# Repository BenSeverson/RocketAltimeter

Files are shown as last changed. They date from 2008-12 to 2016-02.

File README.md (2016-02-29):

High Power Rocket Altimeter
===============
This is an altimeter for [high power rocketry](https://en.wikipedia.org/wiki/High-power_rocketry). Sources include the PIC Micro firmware, Eagle PCB layout, and Windows configuration/log download program.

Features:
- dual payload deployment
- altitude and deployment logging to non-volatile EEPROM
- native USB support for configuration and log downloading
- audible max altitude readout
- pre-launch readiness audible indicator and rocket recovery/location beep
- simple 2-layer PCB with mainly SMT components designed to be made at home

**Note:** I started this project back in 2007 when I was in college but life got in the way before I had a chance to complete it. I've uploaded it here for archival purposes and maybe someone will find it useful. If you are looking for an open source altimeter, I'd highly suggest [Altus Metrum](http://altusmetrum.org/) which is complete, much more advanced, and actually being developed/maintained.

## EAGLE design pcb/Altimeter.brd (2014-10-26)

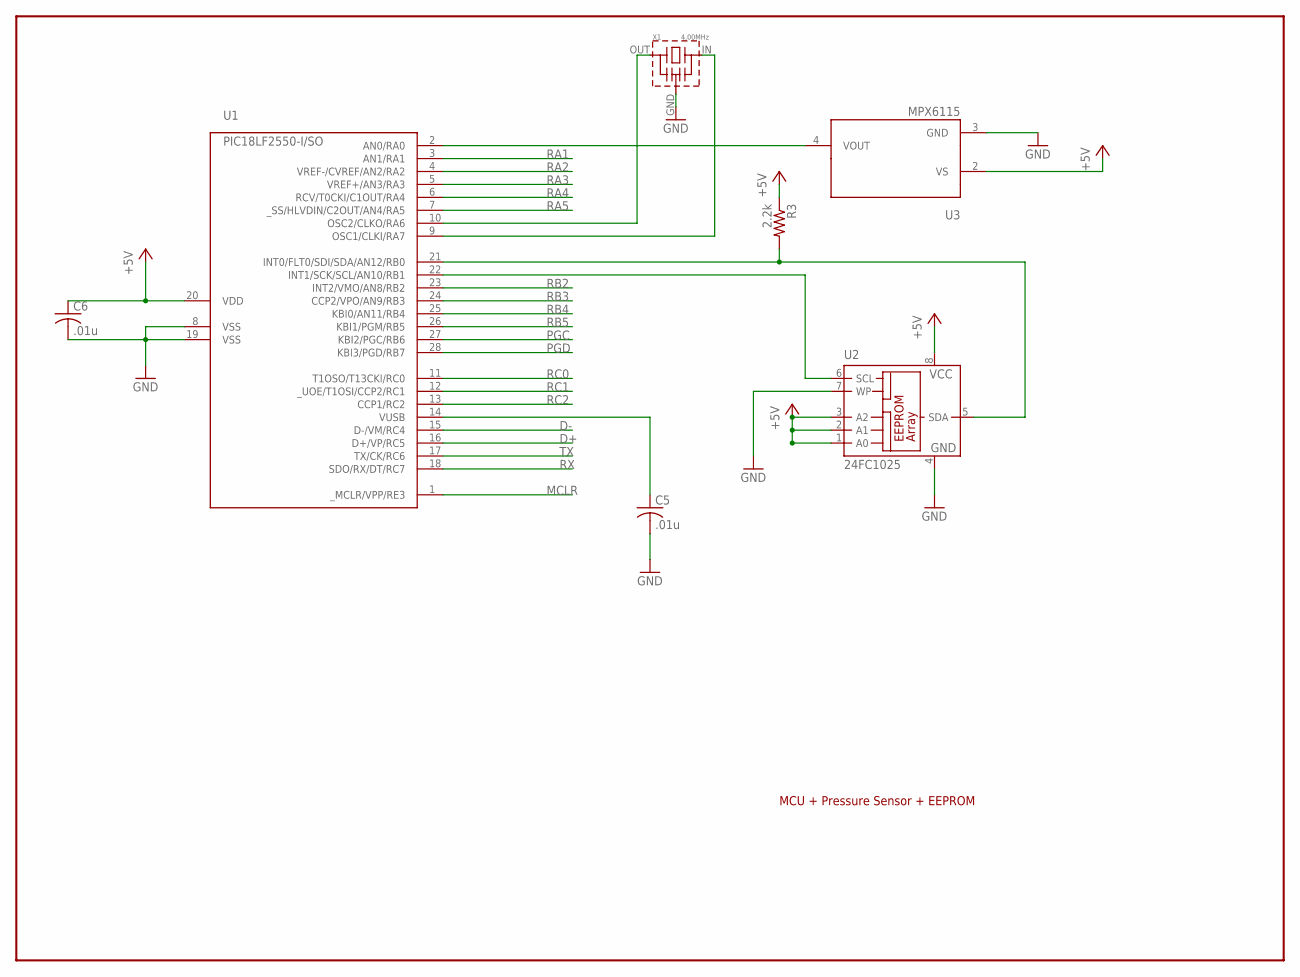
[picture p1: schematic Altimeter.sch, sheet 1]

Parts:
C5, C6: .01u; C1206
R3: 2.2k; R1206
U1: PIC18LF2550-I/SO; SO-28W
U2: 24FC1025; SO-08M
U3: MPX6115; SSOP8
X1: 4.00MHz; 7434

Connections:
+5V: C6.1, R3.1, U1.20 (VDD), U2.1 (A0), U2.2 (A1), U2.3 (A2), U2.8 (VCC), U3.2 (VS); also elsewhere on the board
D+: U1.16 (D+/VP/RC5); also elsewhere on the board
D-: U1.15 (D-/VM/RC4); also elsewhere on the board
GND: C5.2, C6.2, U1.8 (VSS), U1.19 (VSS), U2.4 (GND), U2.7 (WP), U3.3 (GND), X1.GND (VSS); also elsewhere on the board
MCLR: U1.1 (_MCLR/VPP/RE3); also elsewhere on the board
unnamed: U1.2 (AN0/RA0), U3.4 (VOUT)
unnamed: U1.22 (INT1/SCK/SCL/AN10/RB1), U2.6 (SCL)
unnamed: R3.2, U1.21 (INT0/FLT0/SDI/SDA/AN12/RB0), U2.5 (SDA)
unnamed: U1.10 (OSC2/CLKO/RA6), X1.OUT (1)
unnamed: U1.9 (OSC1/CLKI/RA7), X1.IN (3)
unnamed: C5.1, U1.14 (VUSB)
PGC: U1.27 (KBI2/PGC/RB6); also elsewhere on the board
PGD: U1.28 (KBI3/PGD/RB7); also elsewhere on the board
RA1: U1.3 (AN1/RA1)
RA2: U1.4 (VREF-/CVREF/AN2/RA2)
RA3: U1.5 (VREF+/AN3/RA3); also elsewhere on the board
RA4: U1.6 (RCV/T0CKI/C1OUT/RA4); also elsewhere on the board
RA5: U1.7 (_SS/HLVDIN/C2OUT/AN4/RA5)
RB2: U1.23 (INT2/VMO/AN8/RB2); also elsewhere on the board
RB3: U1.24 (CCP2/VPO/AN9/RB3); also elsewhere on the board
RB4: U1.25 (KBI0/AN11/RB4)
RB5: U1.26 (KBI1/PGM/RB5)
RC0: U1.11 (T1OSO/T13CKI/RC0); also elsewhere on the board
RC1: U1.12 (_UOE/T1OSI/CCP2/RC1); also elsewhere on the board
RC2: U1.13 (CCP1/RC2); also elsewhere on the board
RX: U1.18 (SDO/RX/DT/RC7); also elsewhere on the board
TX: U1.17 (TX/CK/RC6); also elsewhere on the board

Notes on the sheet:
MCU + Pressure Sensor + EEPROM

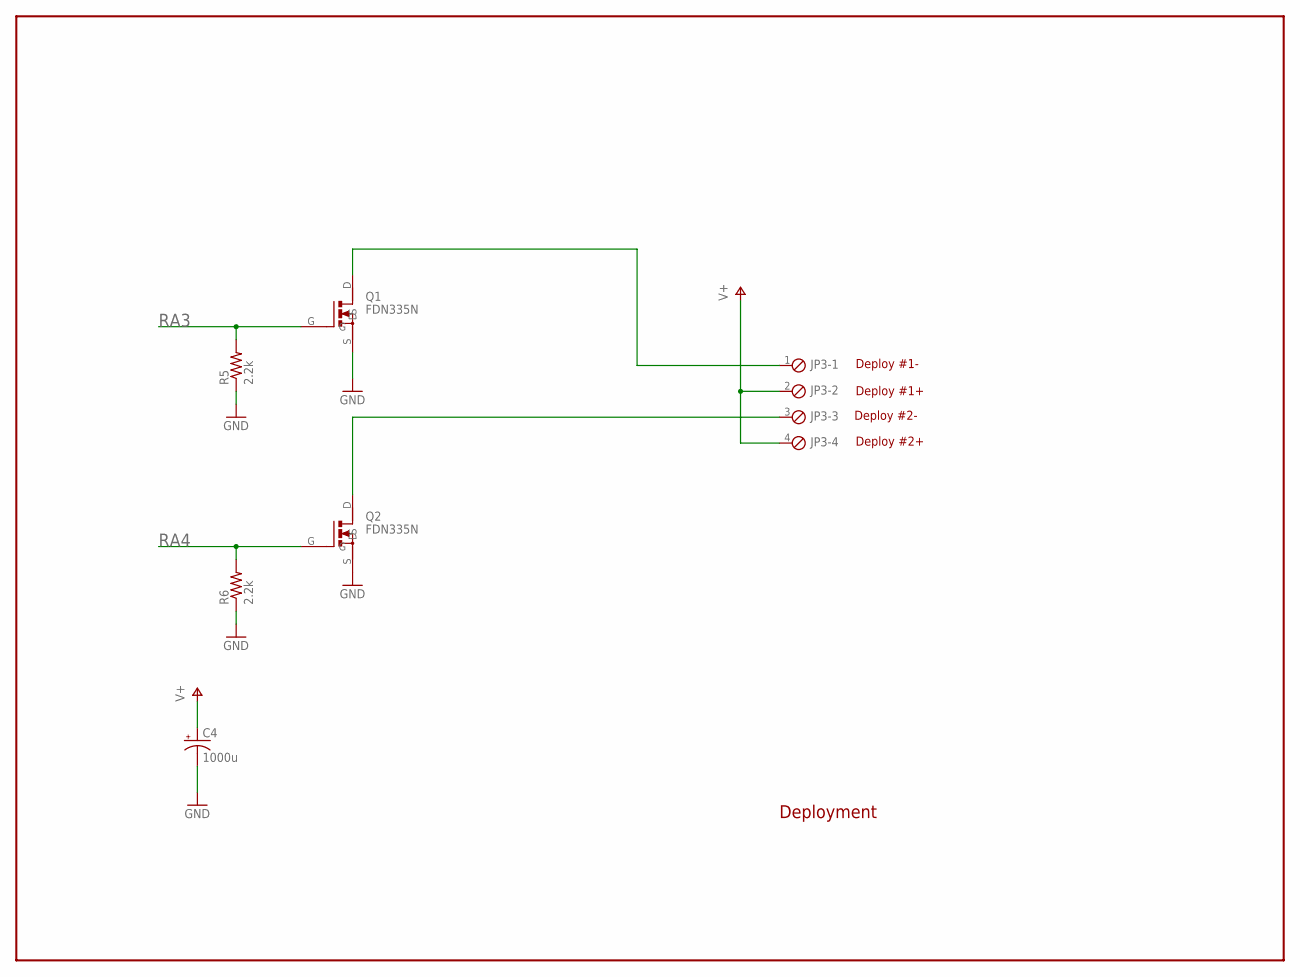
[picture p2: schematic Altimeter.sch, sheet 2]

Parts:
C4: 1000u; PANASONIC_G
JP3: MPT4; 4POL254
Q1, Q2: FDN335N; SSOT3
R5, R6: 2.2k; R1206

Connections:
GND: C4.-, Q1.S, Q2.S, R5.1, R6.1; also elsewhere on the board
unnamed: JP3.1, Q1.D
unnamed: JP3.3, Q2.D
RA3: Q1.G, R5.2; also elsewhere on the board
RA4: Q2.G, R6.2; also elsewhere on the board
V+: C4.+, JP3.2, JP3.4; also elsewhere on the board

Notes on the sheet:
Deployment
Deploy #1-
Deploy #1+
Deploy #2+
Deploy #2-

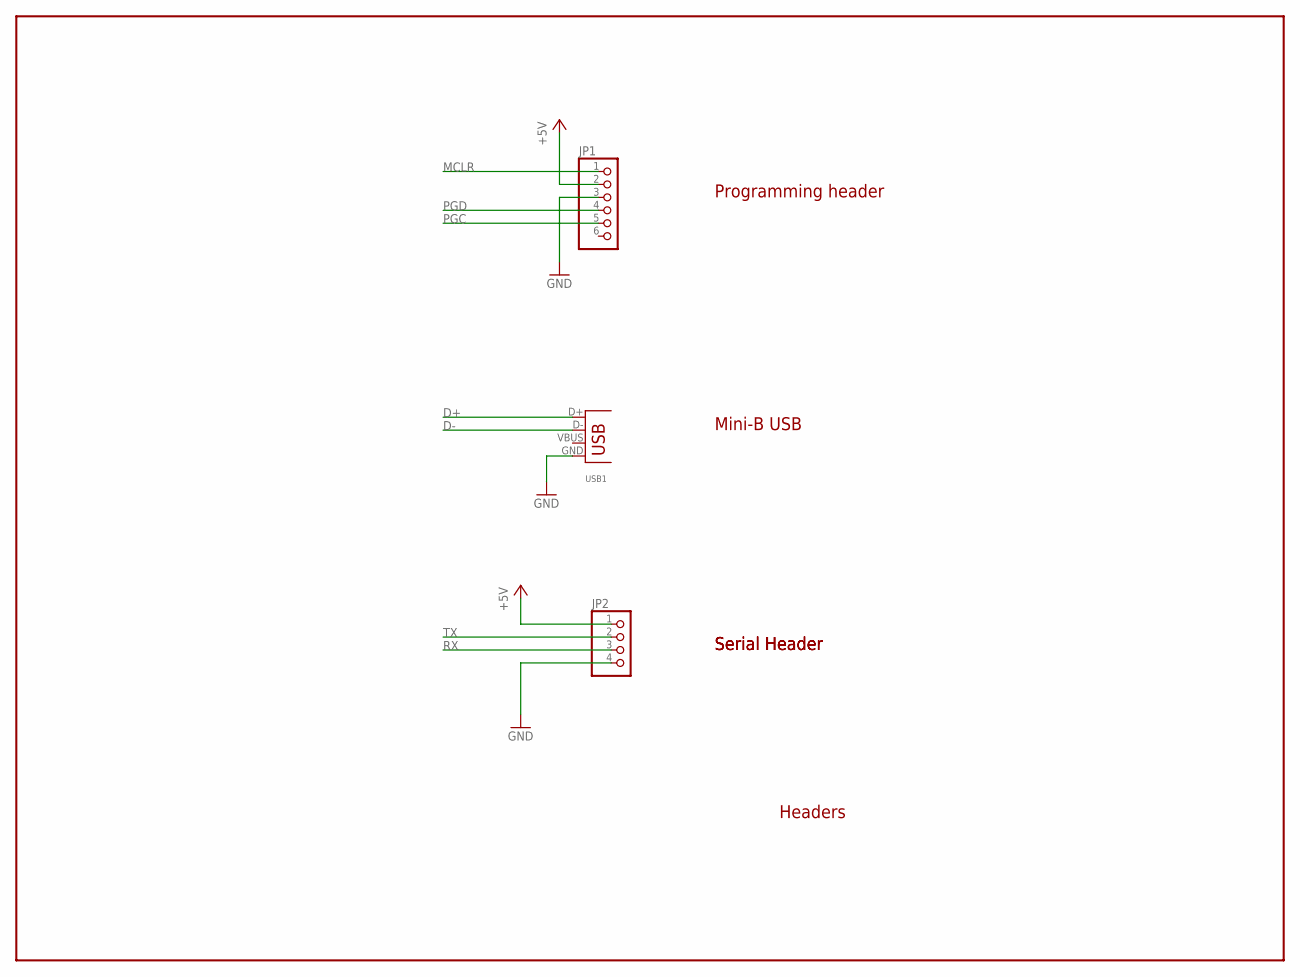
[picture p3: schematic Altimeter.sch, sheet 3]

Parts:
JP1: PINHD-1X6; 1X06
JP2: PINHD-1X4; 1X04
USB1: USB-MB-S

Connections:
+5V: JP1.2, JP2.1; also elsewhere on the board
D+: USB1.D+; also elsewhere on the board
D-: USB1.D-; also elsewhere on the board
GND: JP1.3, JP2.4, USB1.GND; also elsewhere on the board
MCLR: JP1.1; also elsewhere on the board
PGC: JP1.5; also elsewhere on the board
PGD: JP1.4; also elsewhere on the board
RX: JP2.3; also elsewhere on the board
TX: JP2.2; also elsewhere on the board

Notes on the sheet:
Programming header
Mini-B USB
Serial Header
Headers

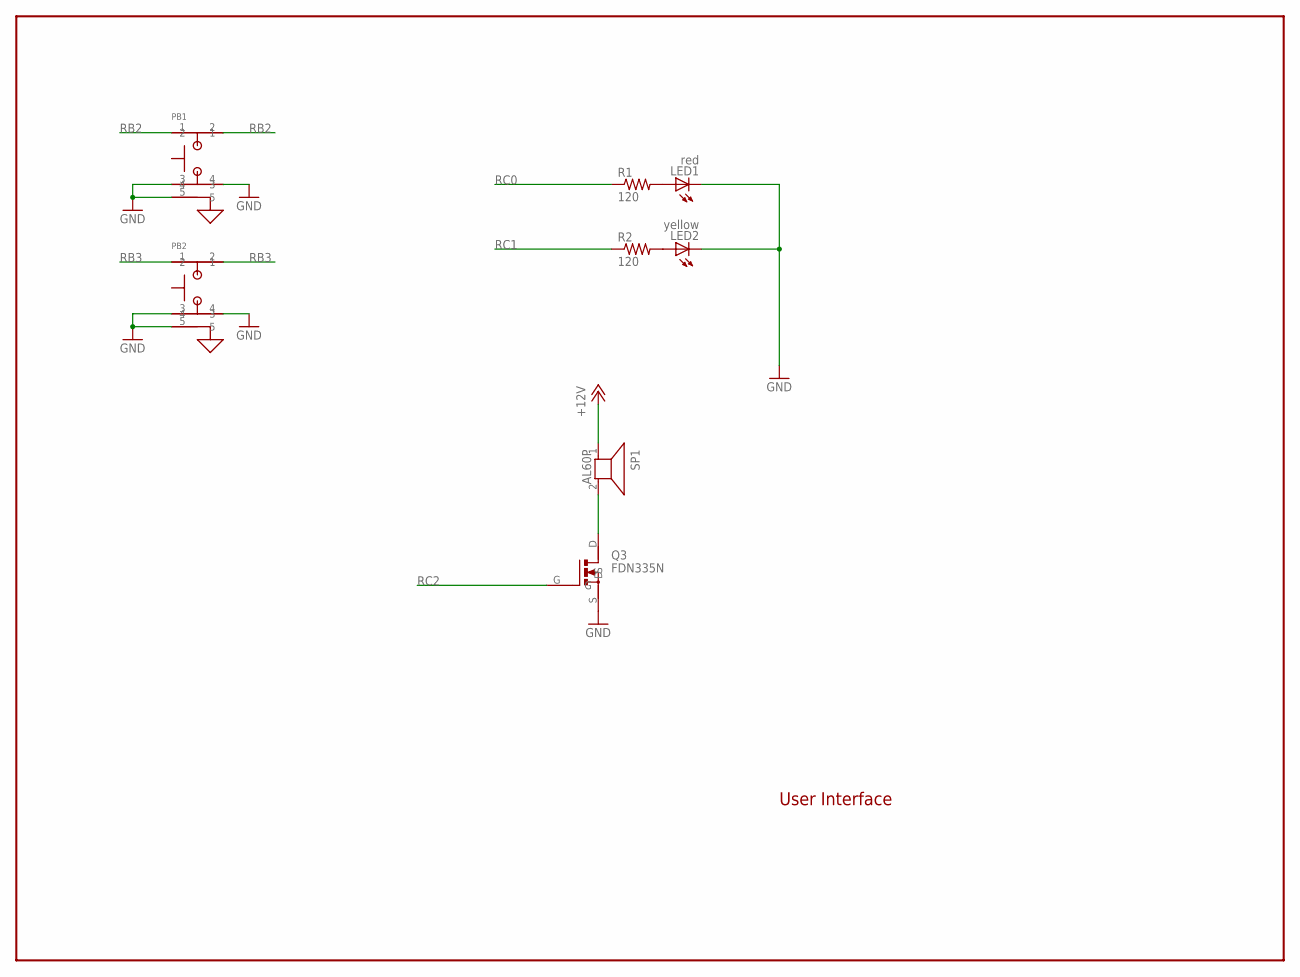
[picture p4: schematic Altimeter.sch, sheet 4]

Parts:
LED1: red; 1206
LED2: yellow; 1206
PB1, PB2: ALPS_SWITCH_SMD; ALPS-SMD-TACT
Q3: FDN335N; SSOT3
R1, R2: 120; R1206
SP1: AL60P; KB-BUZZER

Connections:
+12V: SP1.1; also elsewhere on the board
GND: LED1.C, LED2.C, PB1.3, PB1.4, PB1.5, PB2.3, PB2.4, PB2.5, Q3.S; also elsewhere on the board
unnamed: LED1.A, R1.2
unnamed: LED2.A, R2.2
unnamed: Q3.D, SP1.2
RB2: PB1.1, PB1.2; also elsewhere on the board
RB3: PB2.1, PB2.2; also elsewhere on the board
RC0: R1.1; also elsewhere on the board
RC1: R2.1; also elsewhere on the board
RC2: Q3.G; also elsewhere on the board

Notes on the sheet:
User Interface

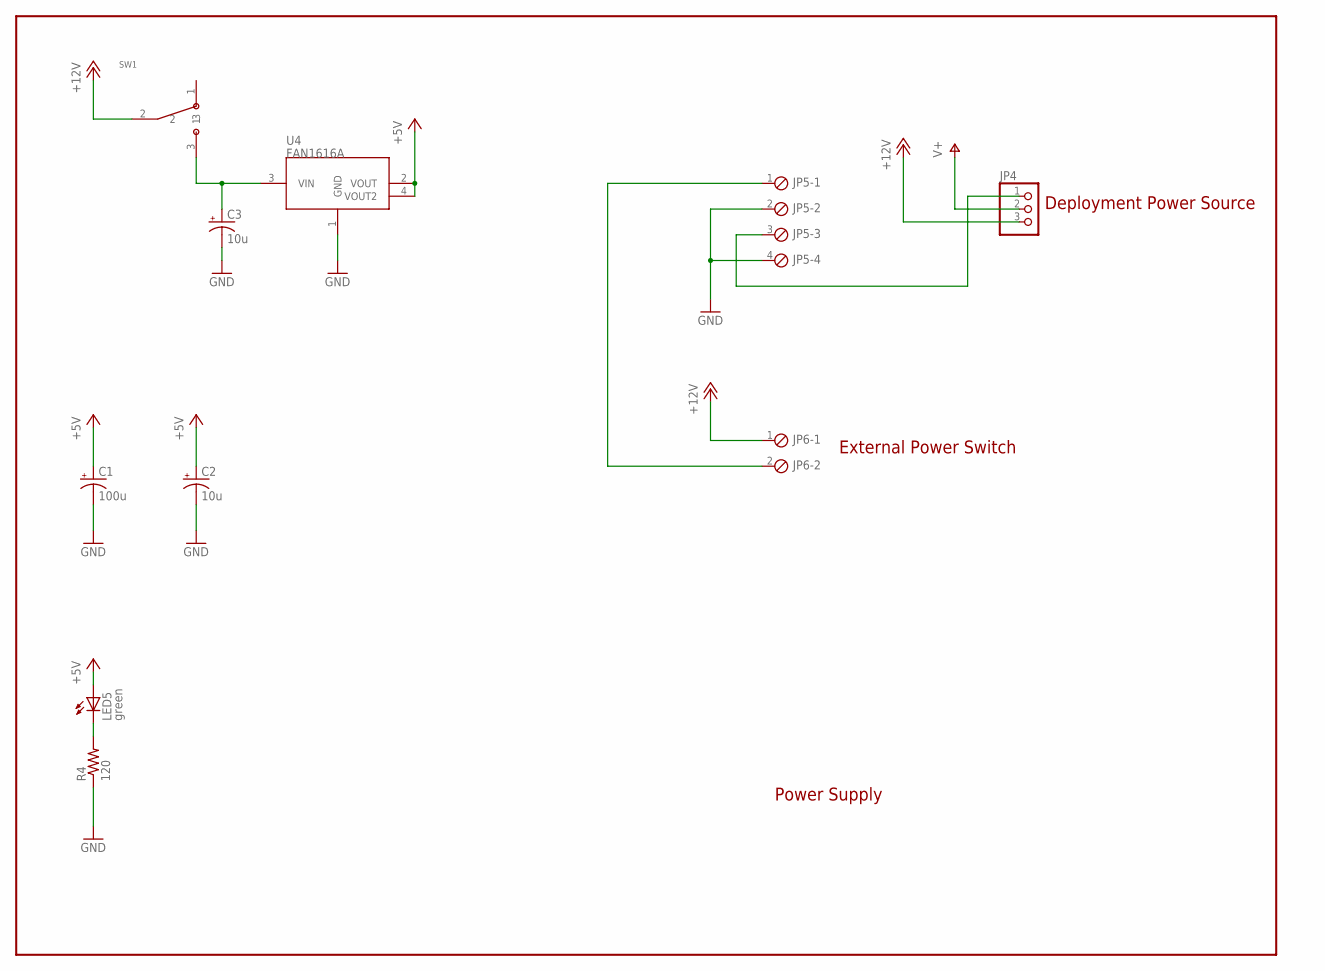
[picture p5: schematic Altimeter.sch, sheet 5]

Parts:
C1: 100u; PANASONIC_D
C2, C3: 10u; PANASONIC_C
JP4: PINHD-1X3; 1X03
JP5: MPT4; 4POL254
JP6: MPT2; 2POL254
LED5: green; 1206
R4: 120; R1206
SW1: EG1218; EG-SWITCH
U4: FAN1616A; SOT223

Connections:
+5V: C1.+, C2.+, LED5.A, U4.2 (VOUT), U4.4 (VOUT2); also elsewhere on the board
+12V: JP4.3, JP6.1, SW1.2; also elsewhere on the board
GND: C1.-, C2.-, C3.-, JP5.2, JP5.4, R4.1, U4.1 (GND); also elsewhere on the board
unnamed: C3.+, SW1.3, U4.3 (VIN)
unnamed: JP5.1, JP6.2
unnamed: JP4.1, JP5.3
unnamed: LED5.C, R4.2
V+: JP4.2; also elsewhere on the board

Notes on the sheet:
External Power Switch
Deployment Power Source
Power Supply

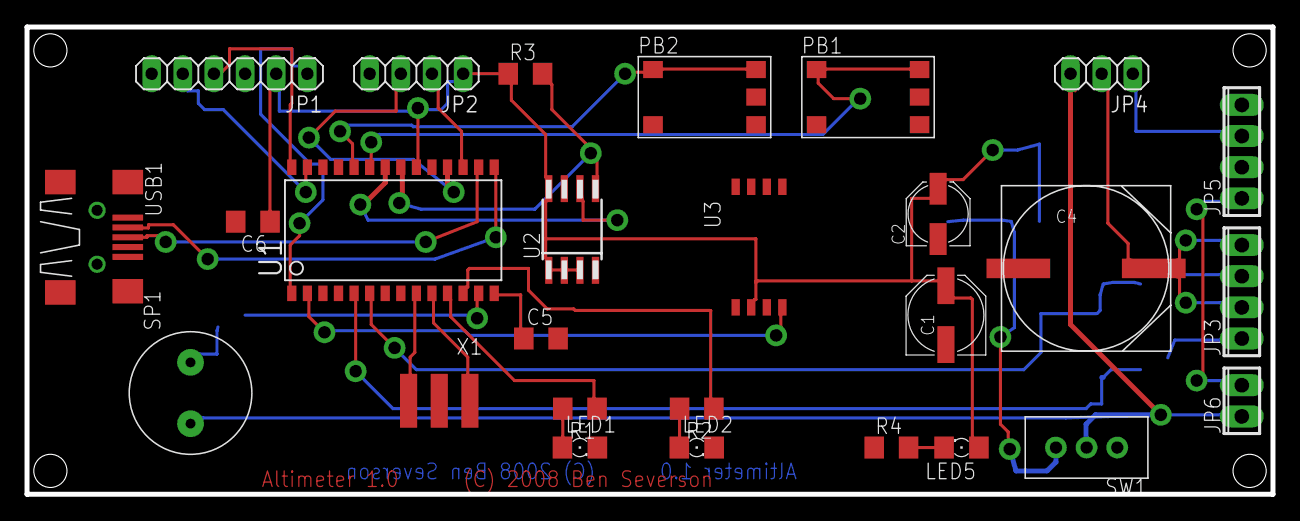
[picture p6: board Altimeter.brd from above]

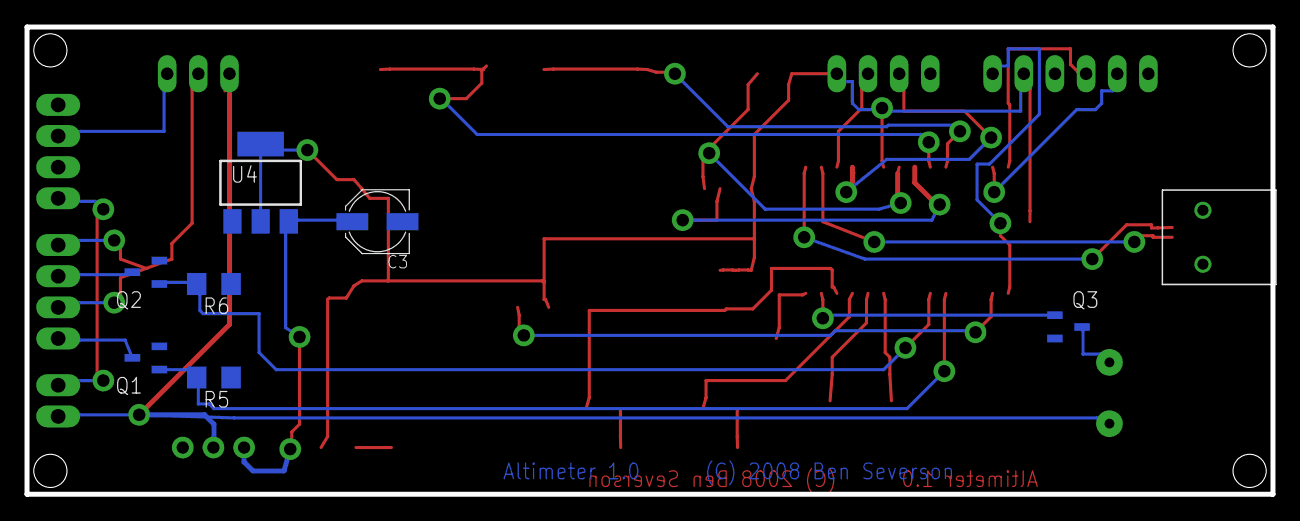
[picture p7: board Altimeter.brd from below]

Board: 2 copper layers, 101.6 x 38.1 mm, 34 parts (7 on the bottom side), 33 nets.

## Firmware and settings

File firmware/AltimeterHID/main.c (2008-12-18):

/** I N C L U D E S **********************************************************/
#include <p18cxxx.h>
#include <timers.h>
#include "system\typedefs.h"                        // Required
#include "system\usb\usb.h"                         // Required
#include "io_cfg.h"                                 // Required

#include "system\usb\usb_compile_time_validation.h" // Optional
#include "user\user.h"                        // Modifiable
//#include "user\lut.h"

/** C O N F I G U R A T I O N ************************************************/

        #pragma config PLLDIV   = 1         // (4 MHz resonator)
        #pragma config CPUDIV   = OSC1_PLL2	
        #pragma config USBDIV   = 2         // Clock source from 96MHz PLL/2
        #pragma config FOSC     = HSPLL_HS
        #pragma config FCMEN    = OFF
        #pragma config IESO     = OFF
        #pragma config PWRT     = OFF
        #pragma config BOR      = ON
        #pragma config BORV     = 3
        #pragma config VREGEN   = ON		//USB Voltage Regulator
        #pragma config WDT      = OFF
        #pragma config WDTPS    = 32768
        #pragma config MCLRE    = OFF		// MCLRE??
        #pragma config LPT1OSC  = OFF
        #pragma config PBADEN   = OFF
//      #pragma config CCP2MX   = ON
        #pragma config STVREN   = ON
        #pragma config LVP      = OFF
//      #pragma config ICPRT    = OFF       // Dedicated In-Circuit Debug/Programming
        #pragma config XINST    = OFF       // Extended Instruction Set
        #pragma config CP0      = OFF
        #pragma config CP1      = OFF
//      #pragma config CP2      = OFF
//      #pragma config CP3      = OFF
        #pragma config CPB      = OFF
//      #pragma config CPD      = OFF
        #pragma config WRT0     = OFF
        #pragma config WRT1     = OFF
//      #pragma config WRT2     = OFF
//      #pragma config WRT3     = OFF
        #pragma config WRTB     = OFF       // Boot Block Write Protection
        #pragma config WRTC     = OFF
//      #pragma config WRTD     = OFF
        #pragma config EBTR0    = OFF
        #pragma config EBTR1    = OFF
//      #pragma config EBTR2    = OFF
//      #pragma config EBTR3    = OFF
        #pragma config EBTRB    = OFF

/** V A R I A B L E S ********************************************************/
#pragma udata

/** P R I V A T E  P R O T O T Y P E S ***************************************/
static void InitializeSystem(void);
void USBTasks(void);

/** V E C T O R  R E M A P P I N G *******************************************/

//extern void _startup (void);        // See c018i.c in your C18 compiler dir
//#pragma code _RESET_INTERRUPT_VECTOR = 0x000800
//void _reset (void)
//{
//    _asm goto _startup _endasm
//}
#pragma code

void timer_isr (void);
#pragma code high_vector=0x08
void high_interrupt (void)
{
	_asm GOTO timer_isr _endasm
}

#pragma code

#pragma interrupt timer_isr
void timer_isr (void)
{

	INTCONbits.TMR0IF = 0;
	TMR0H = 0x8A;
    TMR0L = 0xD8;
	
	////// every 937=200Hz
	////// reload value = 0xFC57
	// every 5ms = 200Hz with prescaler = 2 @ 48MHz
}


/** D E C L A R A T I O N S **************************************************/
#pragma code
/******************************************************************************
 * Function:        void main(void)
 *
 * PreCondition:    None
 *
 * Input:           None
 *
 * Output:          None
 *
 * Side Effects:    None
 *
 * Overview:        Main program entry point.
 *
 * Note:            None
 *****************************************************************************/
void main(void)
{   
    InitializeSystem();
    
    INTCONbits.GIE = 1;
	TMR0H = 0x8A;
    TMR0L = 0xD3;
    while(1)
    {
        USBTasks();         // USB Tasks
        ProcessIO();        // See user\user.c & .h
    }//end while
}//end main

/******************************************************************************
 * Function:        static void InitializeSystem(void)
 *
 * PreCondition:    None
 *
 * Input:           None
 *
 * Output:          None
 *
 * Side Effects:    None
 *
 * Overview:        InitializeSystem is a centralize initialization routine.
 *                  All required USB initialization routines are called from
 *                  here.
 *
 *                  User application initialization routine should also be
 *                  called from here.                  
 *
 * Note:            None
 *****************************************************************************/
static void InitializeSystem(void)
{
    ADCON1 |= 0x0F;                 // Default all pins to digital

//	The USB specifications require that USB peripheral devices must never source
//	current onto the Vbus pin.  Additionally, USB peripherals should not source
//	current on D+ or D- when the host/hub is not actively powering the Vbus line.
//	When designing a self powered (as opposed to bus powered) USB peripheral
//	device, the firmware should make sure not to turn on the USB module and D+
//	or D- pull up resistor unless Vbus is actively powered.  Therefore, the
//	firmware needs some means to detect when Vbus is being powered by the host.
//	A 5V tolerant I/O pin can be connected to Vbus (through a resistor), and
// 	can be used to detect when Vbus is high (host actively powering), or low
//	(host is shut down or otherwise not supplying power).  The USB firmware
// 	can then periodically poll this I/O pin to know when it is okay to turn on
//	the USB module/D+/D- pull up resistor.  When designing a purely bus powered
//	peripheral device, it is not possible to source current on D+ or D- when the
//	host is not actively providing power on Vbus. Therefore, implementing this
//	bus sense feature is optional.  This firmware can be made to use this bus
//	sense feature by making sure "USE_USB_BUS_SENSE_IO" has been defined in the
//	usbcfg.h file.    
    #if defined(USE_USB_BUS_SENSE_IO)
    tris_usb_bus_sense = INPUT_PIN; // See io_cfg.h
    #endif
    
    mInitializeUSBDriver();         // See usbdrv.h
    
    UserInit();                     // See user.c & .h
    
    INTCON2bits.RBPU = 1;
    
    // open timer0 and scale to 187.5kHz (using 48MHz clock as source)
    OpenTimer0 (TIMER_INT_ON & T0_SOURCE_INT & T0_16BIT & T0_PS_1_2);


}//end InitializeSystem

/******************************************************************************
 * Function:        void USBTasks(void)
 *
 * PreCondition:    InitializeSystem has been called.
 *
 * Input:           None
 *
 * Output:          None
 *
 * Side Effects:    None
 *
 * Overview:        Service loop for USB tasks.
 *
 * Note:            None
 *****************************************************************************/
void USBTasks(void)
{
    /*
     * Servicing Hardware
     */
    USBCheckBusStatus();                // Must use polling method
    USBDriverService();                 // Interrupt or polling method

}// end USBTasks

/** EOF main.c ***************************************************************/

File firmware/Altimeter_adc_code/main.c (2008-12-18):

#include <p18f4553.h>
#include <usart.h>
#include <stdio.h>
#include <delays.h>
#include <adc.h>

//#include <pconfig.h>
#define ACCURACY 1000

#pragma config PLLDIV = 1, CPUDIV = OSC1_PLL2, USBDIV = 2
#pragma config FOSC = HSPLL_HS, FCMEN = OFF, IESO = OFF
#pragma config PWRT = ON, BOR = OFF, BORV = 3, VREGEN = ON
#pragma config WDT = OFF, WDTPS = 32768
#pragma config MCLRE = OFF, LPT1OSC = OFF, PBADEN = OFF, CCP2MX = ON
#pragma config STVREN = OFF, LVP = OFF, ICPRT = OFF, XINST = OFF, DEBUG = OFF
#pragma config CP0 = OFF, CP1 = OFF, CP2 = OFF, CP3 = OFF                   // CONFIG5L
#pragma config CPB = OFF, CPD = OFF                                         // CONFIG5H
#pragma config WRT0 = OFF, WRT1 = OFF, WRT2 = OFF, WRT3 = OFF                // CONFIG6L
#pragma config WRTB = OFF, WRTC = OFF, WRTD = OFF                            // CONFIG6H
#pragma config EBTR0 = OFF, EBTR1 = OFF, EBTR2 = OFF, EBTR3 = OFF           // CONFIG7L
#pragma config EBTRB = OFF                                                  // CONFIG7H


void main (void)
{
  /* Make all bits on the Port B (LEDs) output bits.
   * If bit is cleared, then the bit is an output bit.
   */
  unsigned char x;
  int input,i,i2;
  double output;
  TRISD = 0;
  TRISA = 0xFF;
  OpenUSART(USART_TX_INT_OFF & 
            USART_RX_INT_OFF & 
            USART_BRGH_HIGH & 
            USART_CONT_RX & 
            USART_EIGHT_BIT & 
            USART_ASYNCH_MODE, 25);
  Delay10KTCYx(200);
	Delay10KTCYx(200);
	Delay10KTCYx(200);
	Delay10KTCYx(200);
	Delay10KTCYx(200);
	Delay10KTCYx(200);
	Delay10KTCYx(200);
	Delay10KTCYx(200);
	Delay10KTCYx(200);
	Delay10KTCYx(200);
	Delay10KTCYx(200);
	Delay10KTCYx(200);

  /* Reset the LEDs */
	PORTD = 0xFF;
	
	OpenADC(ADC_FOSC_64 & ADC_RIGHT_JUST & ADC_8_TAD, ADC_CH0 & ADC_INT_OFF & ADC_REF_VDD_VSS, ADC_15ANA);
	

	
  while(1)
  {
	Delay10KTCYx(200);
	Delay10KTCYx(200);
	Delay10KTCYx(200);
	Delay10KTCYx(200);
	Delay10KTCYx(200);
	Delay10KTCYx(200);
	  //printf("asdf\n");
	  //puts("test\r");
	  ConvertADC();
	
	while(BusyADC()) {}
	input = ReadADC();
	output = (double)input * 5.0 / 4096.0;
	
	i = (int) output;
	i2 = (int) ((output-i)*ACCURACY);
	printf("AN0 = %d.%03dV \r", i, i2);
  } 
/*  while(1)
  {
    PORTD = 0;
	Delay10KTCYx(200);
	Delay10KTCYx(200);
	Delay10KTCYx(200);
	Delay10KTCYx(200);
	Delay10KTCYx(200);
	Delay10KTCYx(200);
	PORTD = 0xFF;
	Delay10KTCYx(200);
	Delay10KTCYx(200);
	Delay10KTCYx(200);
	Delay10KTCYx(200);
	Delay10KTCYx(200);
	Delay10KTCYx(200);
  }*/
  /* Light the LEDs */
  //PORTB = 0x5A;
  

  while (1)
    ;
}

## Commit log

2008-12-18 Added pcb lib files for safe keeping
2008-12-18 added old adc reading code backup
2008-12-18 adding some old backup usb/i2c code
2008-12-31 * added timer to connect to altimeter * test code to display altitudes
2010-01-27 checking in wrt54g
    [PCB Project1.PrjPCB, PCB1.PcbDoc, PCB2.PcbDoc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]
2014-10-26 initial port from SVN and removal of unrelated files
    [Altimeter.brd, Altimeter.sch, PCB Project1.PrjPCB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]

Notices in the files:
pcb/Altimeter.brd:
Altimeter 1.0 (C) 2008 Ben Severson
